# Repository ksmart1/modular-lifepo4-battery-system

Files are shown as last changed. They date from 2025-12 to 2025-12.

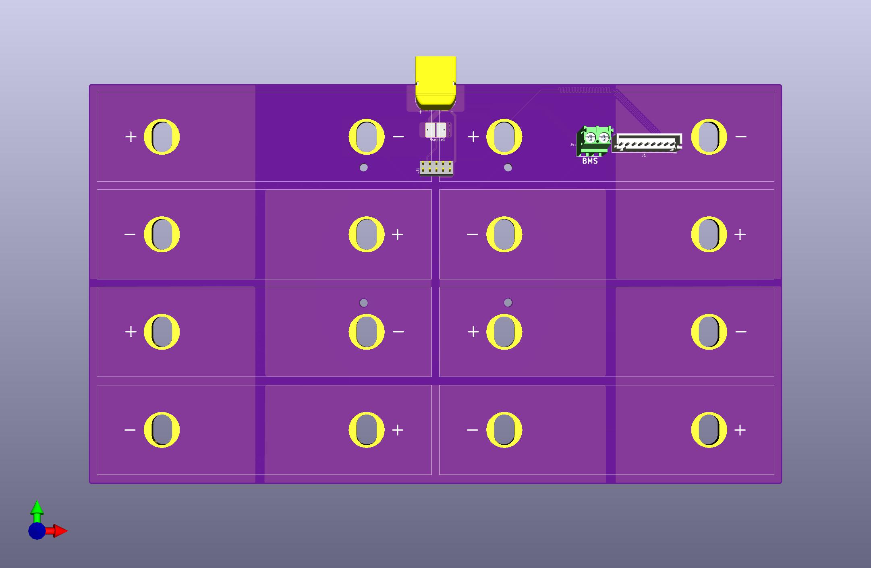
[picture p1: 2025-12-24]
8S_bus_bare.jpg

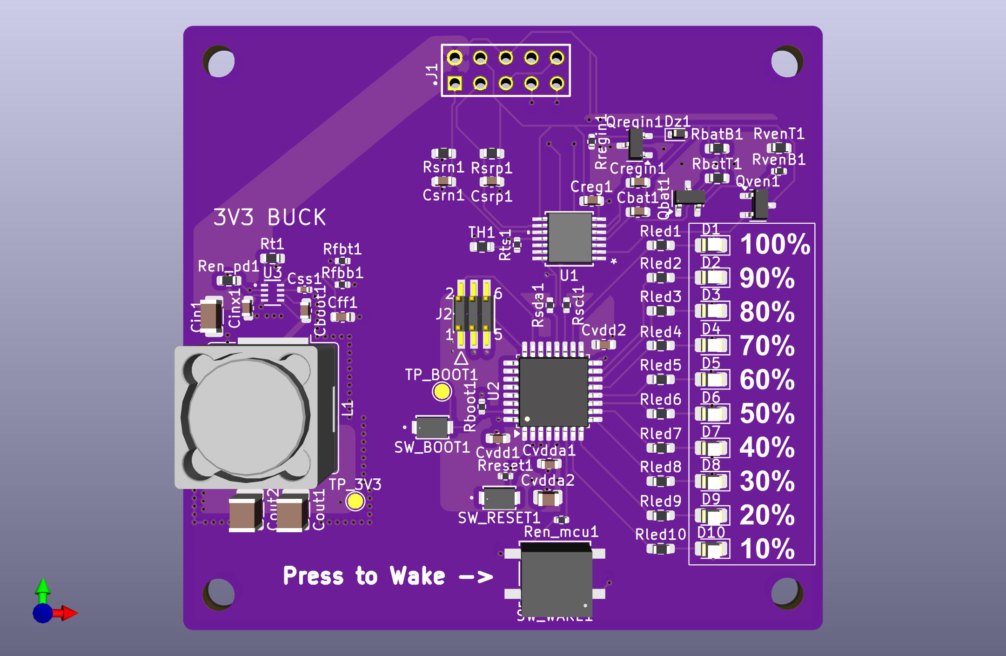
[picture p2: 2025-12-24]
Brain_board.jpg

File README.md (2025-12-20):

# modular-lifepo4-battery-system
A modular LiFePO₄ battery platform with integrated monitoring, protection, and expansion.
 
# Overview

This repository documents the design and implementation of a modular LiFePO₄ battery system intended for portable power, backup energy storage, and future expansion.

The project spans power electronics, PCB design, battery management, manufacturing constraints, and mechanical considerations, and was developed iteratively with a strong emphasis on safety, serviceability, and real-world manufacturability.

## The system is composed of:

  - A battery pack PCB (2-layer and 4-layer variants)

  - A “Brain Board” responsible for regulation, monitoring, and control

  - Optional expansion / I/O boards to support charging and load sharing

  - Future 3D-printed mechanical enclosures

### Key Features

  - LiFePO₄ chemistry for improved safety and cycle life

  - Modular architecture (scalable from 4S to 8S and beyond)

  - Common-port BMS compatibility

  - High-current copper pours and busbar-style routing

  - Sense resistor–based current measurement

  - TVS, fusing, and transient protection

  - Designed for both hand assembly and low-volume fabrication

### System Architecture
  - Battery Pack PCB

  - Supports prismatic LiFePO₄ cells

  - Series connections implemented using large copper pours

  - Balance taps routed cleanly using net ties to avoid schematic ambiguity

  - Sense resistor footprint sized for tens of amps

  - Test points included for validation and debugging

### Designed in both:

  - 2-layer (cost-optimized)

  - 4-layer (improved current return and EMI behavior)

### Protection & Power Path

  - Polyfuse (40A) for fault protection

  - TVS diodes (58V) placed at charge and input connectors

  - Local ceramic decoupling at every high-current connector

### Clear separation between:

  - Battery input

  - Charger input

  - Load output

  - Brain Board

  - Buck regulation for system rails

  - MCU-based control and monitoring

  - Fuel gauge integration (BQ34Z100 family)

  - LED state-of-charge indicators

  - Designed to mate cleanly with multiple battery variants

## Design Considerations

### Manufacturing constraints were a first-class concern:

  - OSH Park vs JLCPCB tradeoffs

  - ENIG vs HASL finish

  - Stencil ordering and hand-assembly feasibility

### Hand soldering viability:

  - Component choices intentionally avoided unnecessary fine-pitch parts

  - Sense resistor installation planned explicitly for hand soldering

### Safety over aesthetics:

  - Wide copper, conservative spacing, robust grounding

### Debuggability:

  - Generous test points

  - Logical net naming

  - Clear silkscreen labeling

  - Mechanical Integration

  - PCB dimensions intentionally oversized relative to cell geometry

  - Designed to bolt into a 3D-printed, topless battery casement

### Enclosure design considers:

  - Foam isolation between cells

  - Modular splitting for printer size limitations

  - Future dovetail or fastener-based joining

### Tools & Technologies

  - KiCad (schematic + PCB layout)

  - OSH Park / JLCPCB (fabrication)

  - Inkscape (labeling / graphics)

  - 3D printing (mechanical planning)

  - Hand SMT soldering (assembly)

## Why This Project Matters

### This project demonstrates:

  - Practical power electronics design

  - Battery system safety awareness

  - PCB layout for high-current applications

  - Iterative engineering problem-solving

  - Comfort across hardware, software-adjacent design, and manufacturing

  - It reflects the type of work required in embedded systems, hardware engineering, robotics, energy systems, and applied cybersecurity/assurance roles where understanding      the entire system matters.

### Status

  - Battery PCB (4S and 8S variants): Complete

  - Expansion / I/O board: Complete

  - Assembly and validation: In progress

  - Enclosure design: Complete

  - Future revisions: Expected

Disclaimer

This project is for educational and experimental purposes.
Working with high-current lithium batteries carries inherent risk.
Use appropriate safety precautions and do not deploy designs without proper validation.

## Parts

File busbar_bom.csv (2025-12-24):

Designator | Footprint | Quantity | Value | LCSC Part #
J1_2 | SAMTEC_DW-05-X-X-D-X | 1 | HW-05-08-F-D-250-SM
J1 | JST_XH_B9B-XH-A_1x09_P2.50mm_Vertical | 1 | Balance Conn
J3 | AMASS_XT60PW-F_1x02_P7.20mm_Horizontal | 1 | XT60
J4 | PHOENIX_1935776 | 1 | BMS
RSENSE1 | RESC_WSHM2818R0150FEA | 1 | 1m 1W 1%

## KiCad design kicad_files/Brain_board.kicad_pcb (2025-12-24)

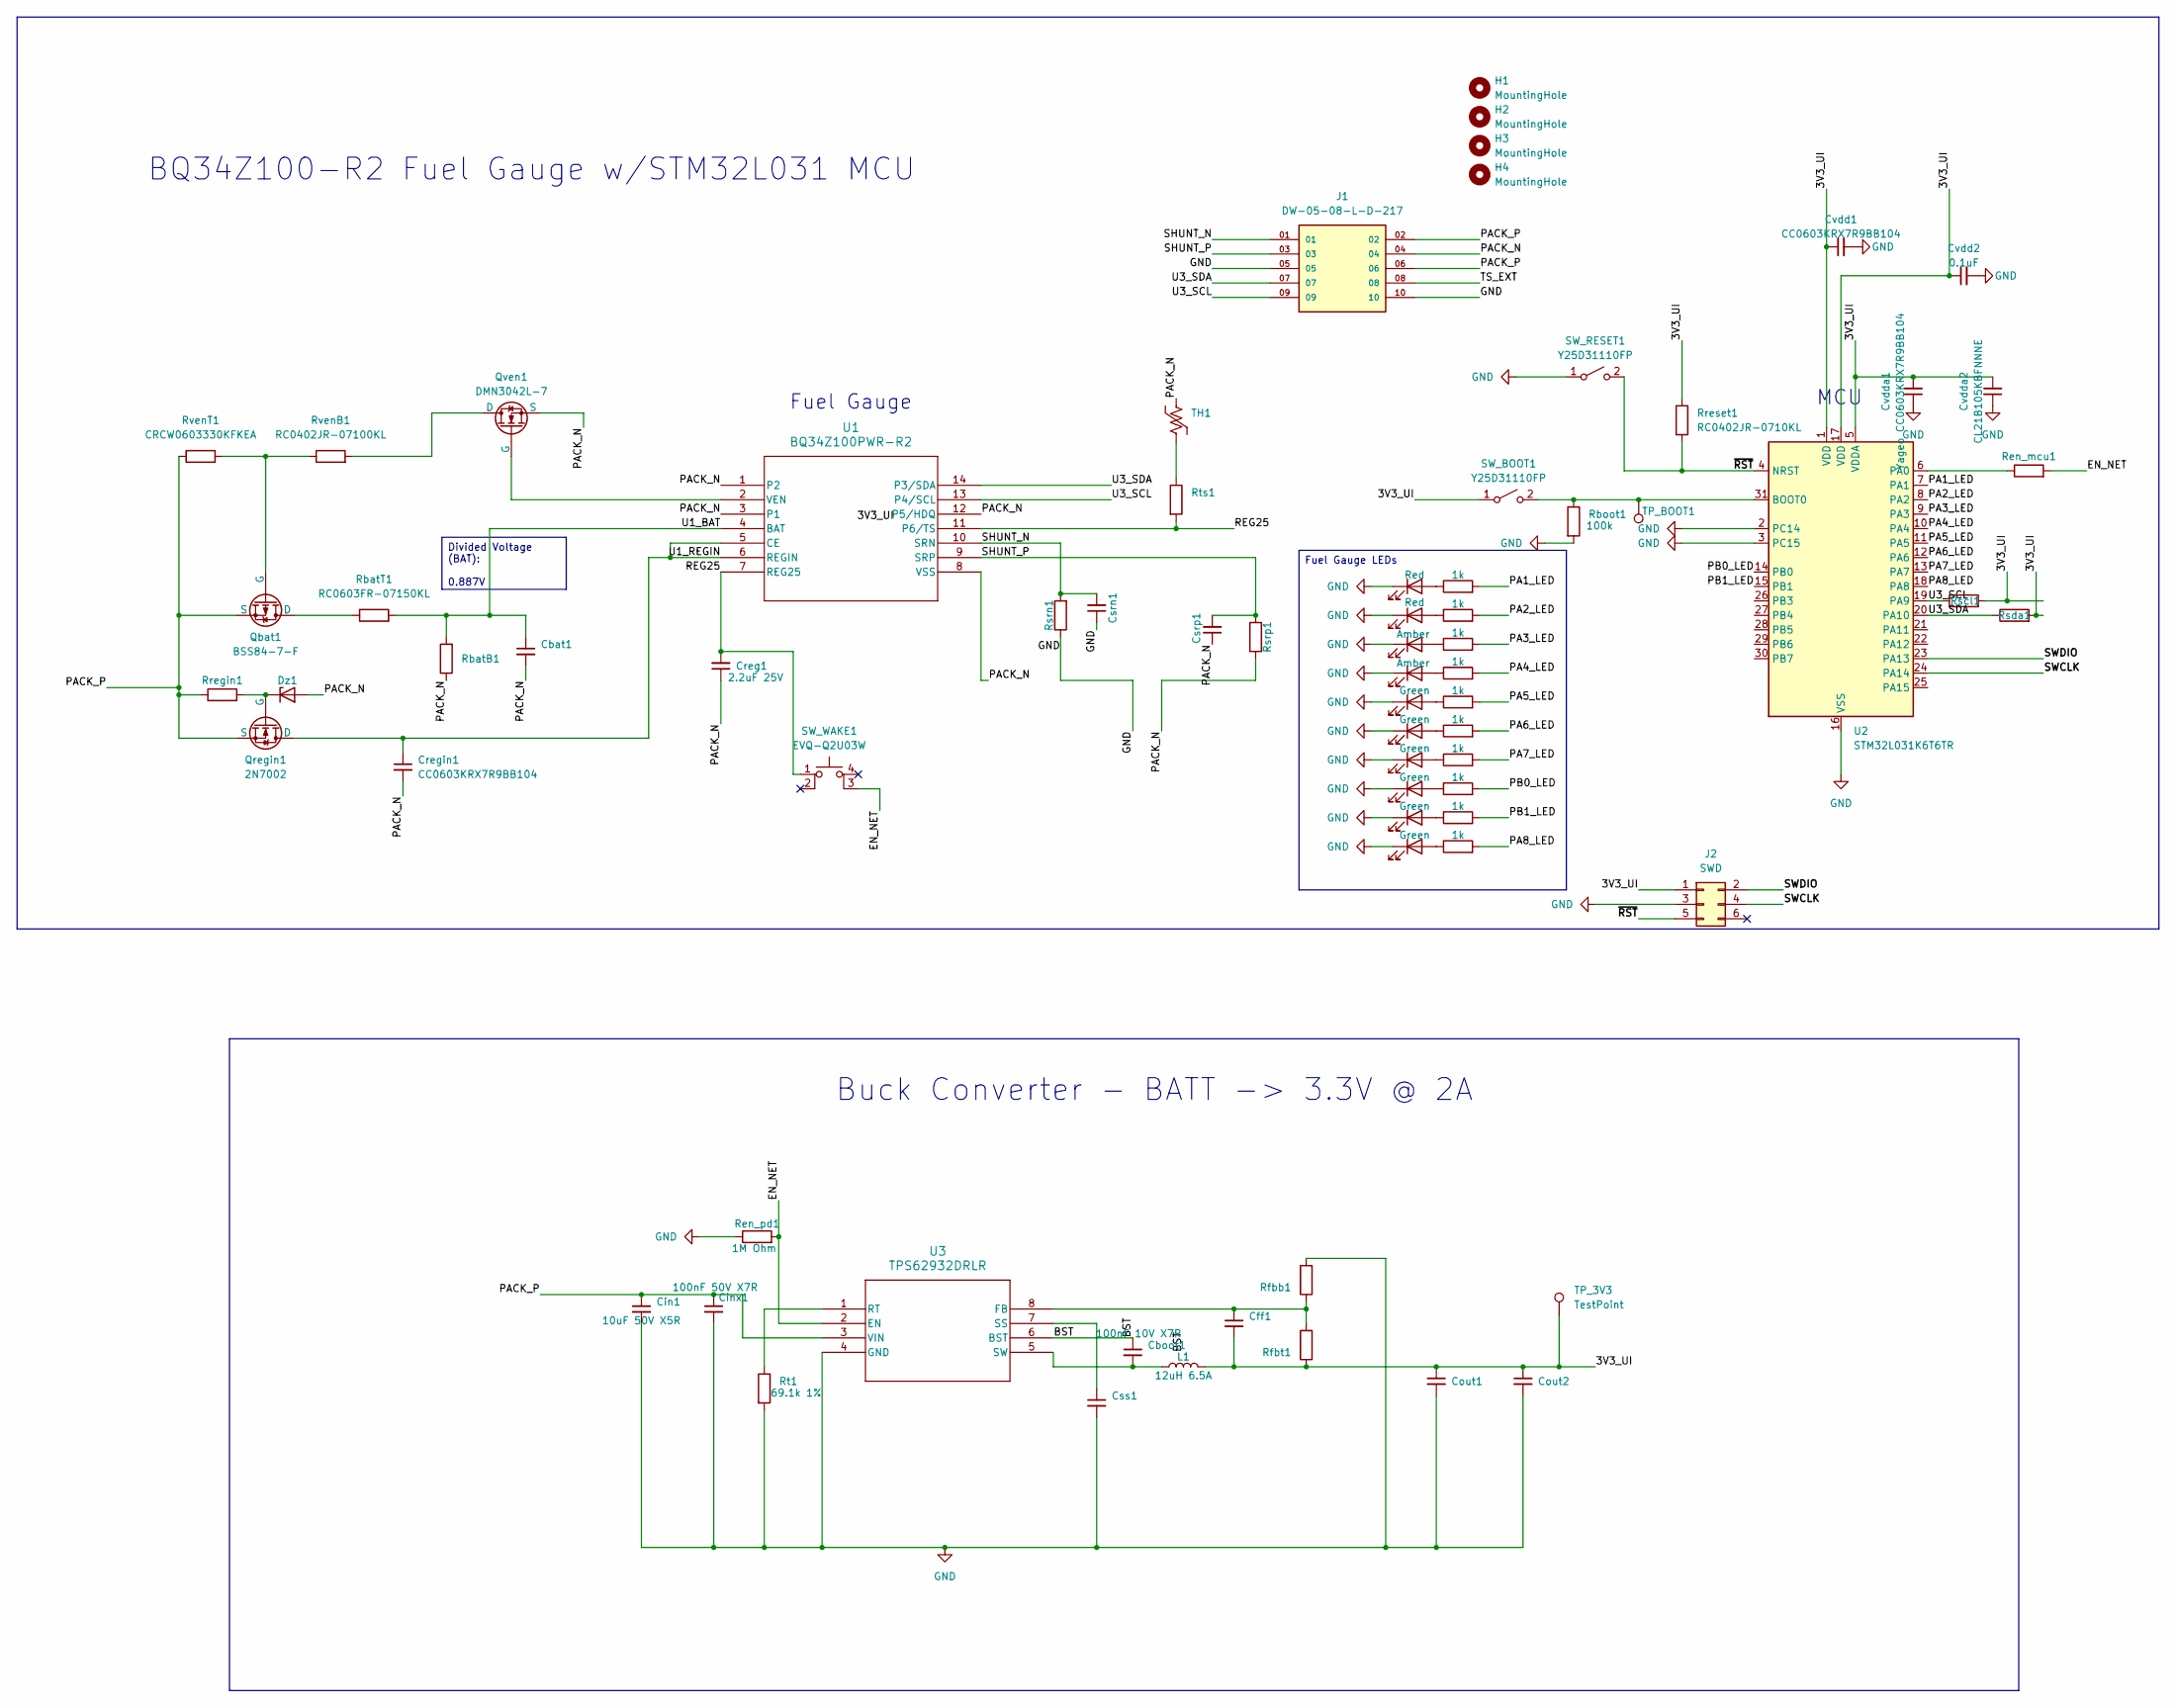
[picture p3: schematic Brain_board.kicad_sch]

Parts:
Cbat1: GRM1885C1H332JA01D; C_0603_1608Metric
Cboot1: CC0603KRX7R9BB104; C_0603_1608Metric
Cff1: C0603C560J5GACTU; C_0603_1608Metric
Cin1: CL31A106KBHNNNE; C_1206_3216Metric
Cinx1: CC0603KRX7R9BB104; C_0603_1608Metric
Cout1: GRM31CR61A476ME15L; C_1210_3225Metric
Cout2: GRM32ER61C476KE15L; C_1210_3225Metric
Creg1: GMC10X7R225K25NT; C_0603_1608Metric
Cregin1: CC0603KRX7R9BB104; C_0603_1608Metric
Csrn1: CC0603KRX7R9BB104; C_0603_1608Metric
Csrp1: CC0603KRX7R9BB104; C_0603_1608Metric
Css1: GRM155R71A333KA01D; C_0402_1005Metric
Cvdd1: CC0603KRX7R9BB104; C_0603_1608Metric
Cvdd2: 0.1uF; C_0603_1608Metric
Cvdda1: Yageo CC0603KRX7R9BB104; C_0603_1608Metric
Cvdda2: CL21B105KBFNNNE; C_0805_2012Metric
D1, D2, D3, D4, D5, D6: 5988170107F; LED_0805_2012Metric_Pad1.15x1.40mm_HandSolder
D7, D8: B1701UY--20D000214U1930; LED_0805_2012Metric_Pad1.15x1.40mm_HandSolder
D9, D10: B1701URO-20D000114U1930; LED_0805_2012Metric_Pad1.15x1.40mm_HandSolder
Dz1: BZT52C5V6T-7; D_SOD-523
H1, H2, H3, H4: MountingHole; MountingHole_3.2mm_M3
J1: DW-05-08-L-D-217; SAMTEC_DW-05-X-X-D-X; PARTREV 01-06-94
J2: SWD; CON6_2X3_DU_FTSH_SAI
L1: SRR1208-120ML; L_Bourns_SRR1208_12.7x12.7mm
Qbat1: BSS84-7-F; SOT-23-3
Qregin1: 2N7002; SOT-23-3
Qven1: DMN3042L-7; SOT-23-3
RbatB1: RC0603FR-074K7L; R_0603_1608Metric
RbatT1: RC0603FR-07150KL; R_0603_1608Metric
Rboot1: RC0402JR-07100KL; R_0402_1005Metric
Ren_mcu1: RC0402JR-0710KL; R_0402_1005Metric
Ren_pd1: CRCW06031M00FKEA; R_0603_1608Metric
Rfbb1: RC0402JR-0710KL; R_0402_1005Metric
Rfbt1: CRCW040230K9FKED; R_0402_1005Metric
Rled1, Rled2, Rled3, Rled4, Rled5, Rled6, Rled7, Rled8, Rled9, Rled10: RMCF0603FT1K00; R_0603_1608Metric_Pad0.98x0.95mm_HandSolder
Rregin1: RC0402JR-0710KL; R_0402_1005Metric
Rreset1: RC0402JR-0710KL; R_0402_1005Metric
Rscl1: RC0603FR-074K7L; R_0402_1005Metric
Rsda1: RC0603FR-074K7L; R_0402_1005Metric
Rsrn1: CRCW0603100RFKEA; R_0603_1608Metric
Rsrp1: CRCW0603100RFKEA; R_0603_1608Metric
Rt1: CRCW060361K9FKEA; R_0603_1608Metric
Rts1: RC0402JR-0710KL; R_0402_1005Metric
RvenB1: RC0402JR-07100KL; R_0402_1005Metric
RvenT1: CRCW0603330KFKEA; R_0603_1608Metric
SW_BOOT1: Y25D31110FP; KXT 311 LHS_CNK
SW_RESET1: Y25D31110FP; KXT 311 LHS_CNK
SW_WAKE1: EVQ-Q2U03W; EVQQ2_3_PAN
TH1: 103KT1608T-1P; R_0603_1608Metric
TP_3V3: TestPoint; TestPoint_Pad_D1.5mm
TP_BOOT1: TestPoint; TestPoint_Pad_D1.5mm
U1: BQ34Z100PWR-R2; PW14_TEX
U2: STM32L031K6T6TR; LQFP-32_7x7mm_P0.8mm
U3: TPS62932DRLR; SOT8_DRL_TEX

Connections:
/3V3_UI: Cff1.2, Cout1.1, Cout2.1, Cvdd1.1, Cvdd2.1, Cvdda1.2, Cvdda2.2, J2.1, L1.2, Rfbt1.1, Rreset1.1, Rscl1.2, Rsda1.2, SW_BOOT1.1 (A), TP_3V3.1, U2.1 (VDD), U2.5 (VDDA), U2.17 (VDD)
/BST: Cboot1.1, U3.6 (BST)
/EN_NET: Ren_mcu1.2, Ren_pd1.2, SW_WAKE1.3 (K), U3.2 (EN)
/PA1_LED: Rled10.2, U2.7 (PA1)
/PA2_LED: Rled9.2, U2.8 (PA2)
/PA3_LED: Rled8.2, U2.9 (PA3)
/PA4_LED: Rled7.2, U2.10 (PA4)
/PA5_LED: Rled6.2, U2.11 (PA5)
/PA6_LED: Rled5.2, U2.12 (PA6)
/PA7_LED: Rled4.2, U2.13 (PA7)
/PA8_LED: Rled1.2, U2.18 (PA8)
/PACK_N: Cbat1.2, Creg1.1, Cregin1.2, Csrp1.1, Dz1.2 (A), J1.04, Qven1.3 (S), RbatB1.1, Rsrp1.1, TH1.1, U1.1 (P2), U1.3 (P1), U1.8 (VSS), U1.12 (P5/HDQ)
/PACK_P: Cin1.1, Cinx1.1, J1.02, J1.06, Qbat1.3 (S), Qregin1.3 (S), Rregin1.1, RvenT1.1, U3.3 (VIN)
/PB0_LED: Rled3.2, U2.14 (PB0)
/PB1_LED: Rled2.2, U2.15 (PB1)
/REG25: Creg1.2, Rts1.2, SW_WAKE1.1, U1.7 (REG25), U1.11 (P6/TS)
/SHUNT_N: Csrn1.2, J1.01, Rsrn1.2, U1.10 (SRN)
/SHUNT_P: Csrp1.2, J1.03, Rsrp1.2, U1.9 (SRP)
/SWCLK: J2.4, U2.24 (PA14)
/SWDIO: J2.2, U2.23 (PA13)
/TS_EXT: J1.08
/U1_BAT: Cbat1.1, RbatB1.2, RbatT1.2, U1.4 (BAT)
/U1_REGIN: Cregin1.1, Qregin1.1 (D), U1.5 (CE), U1.6 (REGIN)
/U3_SCL: J1.09, Rscl1.1, U1.13 (P4/SCL), U2.19 (PA9)
/U3_SDA: J1.07, Rsda1.1, U1.14 (P3/SDA), U2.20 (PA10)
/~RST: J2.5, Rreset1.2, SW_RESET1.2 (B), U2.4 (NRST)
GND: Cin1.2, Cinx1.2, Cout1.2, Cout2.2, Csrn1.1, Css1.2, Cvdd1.2, Cvdd2.2, Cvdda1.1, Cvdda2.1, D1.1 (K), D2.1 (K), D3.1 (K), D4.1 (K), D5.1 (K), D6.1 (K), D7.1 (K), D8.1 (K), D9.1 (K), D10.1 (K), J1.05, J1.10, J2.3, Rboot1.2, Ren_pd1.1, Rfbb1.2, Rsrn1.1, Rt1.2, SW_RESET1.1 (A), U2.2 (PC14), U2.3 (PC15), U2.16 (VSS), U2.32 (VSS), U3.4 (GND)
unnamed: D1.2 (A), Rled1.1
unnamed: D2.2 (A), Rled2.1
unnamed: D3.2 (A), Rled3.1
unnamed: D4.2 (A), Rled4.1
unnamed: D5.2 (A), Rled5.1
unnamed: D6.2 (A), Rled6.1
unnamed: D7.2 (A), Rled7.1
unnamed: D8.2 (A), Rled8.1
unnamed: D9.2 (A), Rled9.1
unnamed: D10.2 (A), Rled10.1
unnamed: Dz1.1 (K), Qregin1.2 (G), Rregin1.2
unnamed: Qbat1.1 (D), RbatT1.1
unnamed: Qbat1.2 (G), RvenB1.1, RvenT1.2
unnamed: Qven1.1 (D), RvenB1.2
unnamed: Qven1.2 (G), U1.2 (VEN)
unnamed: Rts1.1, TH1.2
unnamed: Rboot1.1, SW_BOOT1.2 (B), TP_BOOT1.1, U2.31 (BOOT0)
unnamed: Ren_mcu1.1, U2.6 (PA0)
unnamed: Cff1.1, Rfbb1.1, Rfbt1.2, U3.8 (FB)
unnamed: Rt1.1, U3.1 (RT)
unnamed: Css1.1, U3.7 (SS)
unnamed: Cboot1.2, L1.1, U3.5 (SW)

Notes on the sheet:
Fuel Gauge
BQ34Z100-R2 Fuel Gauge w/STM32L031 MCU
MCU
Buck Converter - BATT -> 3.3V @ 2A
Divided Voltage (BAT): 0.887V
Fuel Gauge LEDs

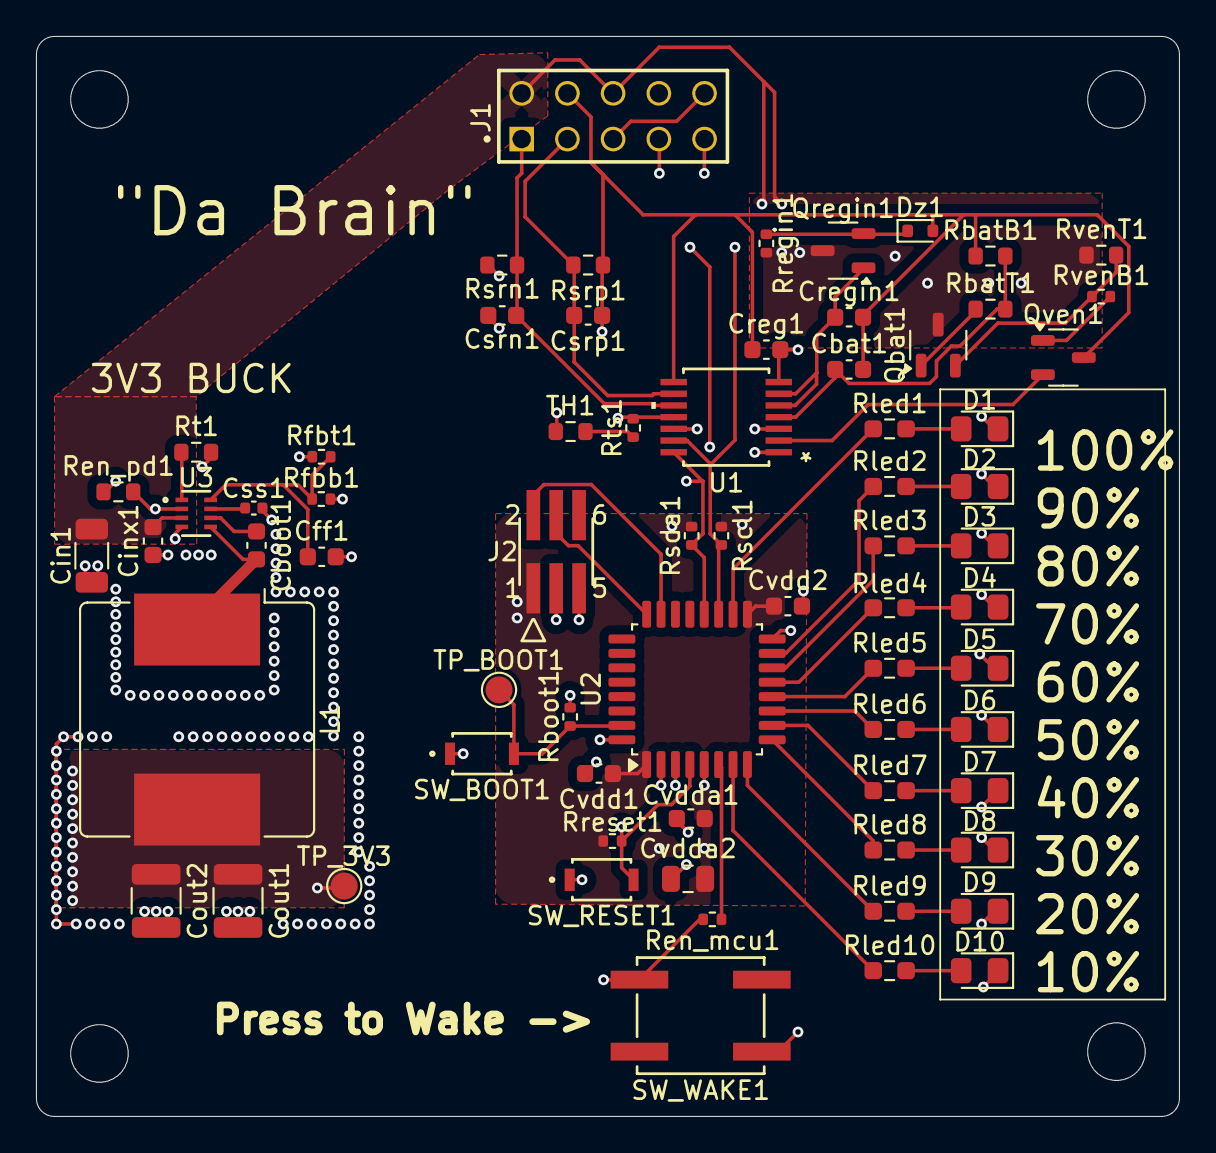
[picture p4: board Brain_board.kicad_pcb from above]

Board: 4 copper layers, 63.5 x 60.0 mm, 73 parts (0 on the bottom side), 48 nets.

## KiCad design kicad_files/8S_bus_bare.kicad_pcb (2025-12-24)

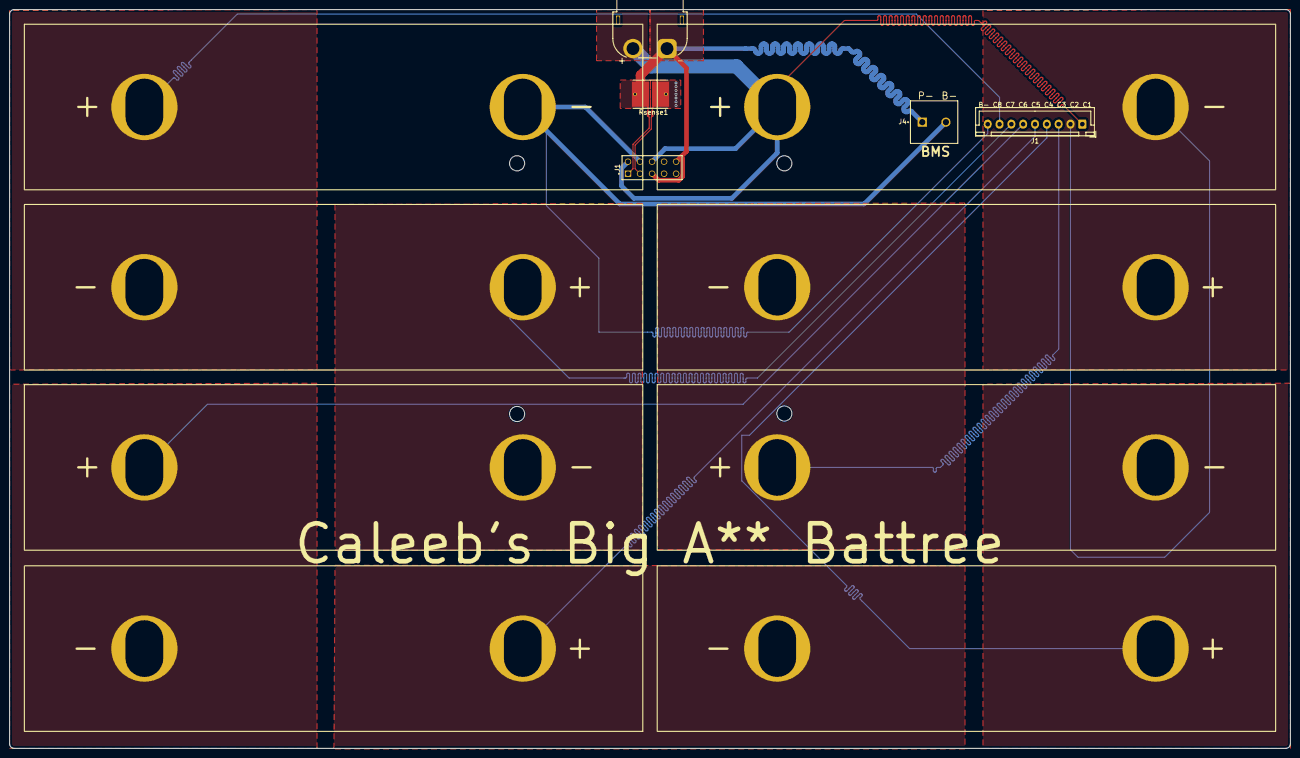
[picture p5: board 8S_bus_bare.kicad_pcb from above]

Board: 2 copper layers, 270.8 x 156.2 mm, 17 parts (0 on the bottom side), 10 nets.

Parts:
BT1, BT2, BT3, BT4, BT5, BT6, BT7, BT8: Battery_Cell; Battery_Narada_50Ah_LiFePO4
H1, H2, H3, H4: MountingHole; MountingHole_3.2mm_M3
J1: HW-05-08-F-D-250-SM; SAMTEC_DW-05-X-X-D-X
J1#2: Balance Conn; JST_XH_B9B-XH-A_1x09_P2.50mm_Vertical
J3: XT60; AMASS_XT60PW-F_1x02_P7.20mm_Horizontal
J4: BMS; PHOENIX_1935776
Rsense1: 1m 1W 1%; RESC_WSHM2818R0150FEA

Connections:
/BT1+: BT1.1 (+), BT2.2 (-), J1#2.8
/BT2+: BT2.1 (+), BT3.2 (-), J1#2.7
/BT3+: BT3.1 (+), BT4.2 (-), J1#2.6
/BT4+: BT4.1 (+), BT5.2 (-), J1#2.5
/BT5+: BT5.1 (+), BT6.2 (-), J1#2.4
/BT6+: BT6.1 (+), BT7.2 (-), J1#2.3
/BT7+: BT7.1 (+), BT8.2 (-), J1#2.2
/PACK_N: BT1.2 (-), J1.04, J1#2.9, J4.2, Rsense1.1, Rsense1.2
/PACK_P: BT8.1 (+), J1.02, J1.06, J1#2.1, J3.2
GND: J1.05, J1.10, J3.1, J4.1, Rsense1.3, Rsense1.4

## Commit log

2025-12-24 Update and rename bom.csv to busbar_bom.csv
    [busbar_bom.csv]
2025-12-24 Add busbar_positions.csv file
    [busbar_positions.csv]
2025-12-24 Update and rename positions.csv to BrainBoard_positions.csv
    [BrainBoard_positions.csv]
